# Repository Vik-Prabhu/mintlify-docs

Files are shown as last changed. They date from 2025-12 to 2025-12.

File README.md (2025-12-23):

# Smart Fault Detector

## Project Description

The **Smart-Fault-Detector** is a specialized diagnostic device engineered to detect actuator faults and failures in high-stakes systems like rockets and robotics. By monitoring the "pulse" of an actuator through electrical and mechanical sensors, it identifies anomalies before they lead to catastrophic system failure.

## 📘 Project Documentation & Deployment

### 🌐 Documentation (Mintlify)

This project uses **Mintlify** to host clean, modern documentation.

- Built using MDX
- Supports images, code blocks, and downloadable assets
- Automatically deployed on every update

**Documentation URL:**  https://teamrobomanipal-3a657712.mintlify.app/Introduction

````
To run docs locally:
npm install
mintlify dev
````

---

### 🚀 Backend Deployment (Render + Flask)

The backend is a **Flask + Socket.IO** server deployed on **Render**.

#### Why Render?

- Free tier support
- Simple GitHub integration
- Works well with Flask APIs
- Public endpoint accessible by ESP devices

#### Tech Stack

- Python
- Flask
- Flask-SocketIO
- Eventlet
- Render Web Service

#### Deployment Flow

1. Push code to GitHub
2. Create a **Web Service** on Render
3. Render installs dependencies from `requirements.txt`
4. App runs on a public HTTPS URL

 **Dashboard URL:** https://mintlify-docs-w26p.onrender.com

---

### 📡 ESP ↔ Server Communication

- ESP device sends data via HTTP / Socket.IO

- Flask server receives and processes data

- Real-time updates supported using WebSockets
- Designed for low-latency actuator/health monitoring

---

### 📂 Key Files

```text
.
├── Firmware            # Contains ESP32-C3 Code
├── PCB                 # KiCAD Design Files
```

```
.
├── docs.json             # Contains structured metadata for the project 
├── package-lock.json     # Auto-generated file for mintlify
```

```
Dashboard_src
├── server.py              # Webserver UI
├── health_model.py        # Predictive Algorithm
├── requirements.txt       # Python dependencies
```

---

### 🛠️ requirements.txt

```txt
flask
flask-socketio
eventlet
```

---

### ✅ Status

- [x] Backend deployed on Render
- [x] Documentation live on Mintlify
- [x] ESP integration working

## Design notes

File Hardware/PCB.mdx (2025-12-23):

---
title: "PCB"
---
#  Hardware Architecture Breakdown

---

## 1. Overview
The Smart Fault Detector is a modular health-monitoring device designed to detect actuator faults and failures in mission-critical environments such as rockets, rovers, and base stations. It fuses electrical telemetry such as voltage and current drawn by the actuator with mechanical data such as rpm and vibration around the actuator to determine if an actuator is operating within safety parameters and predicts the estimated time to failure.

---

## 2. Schematics
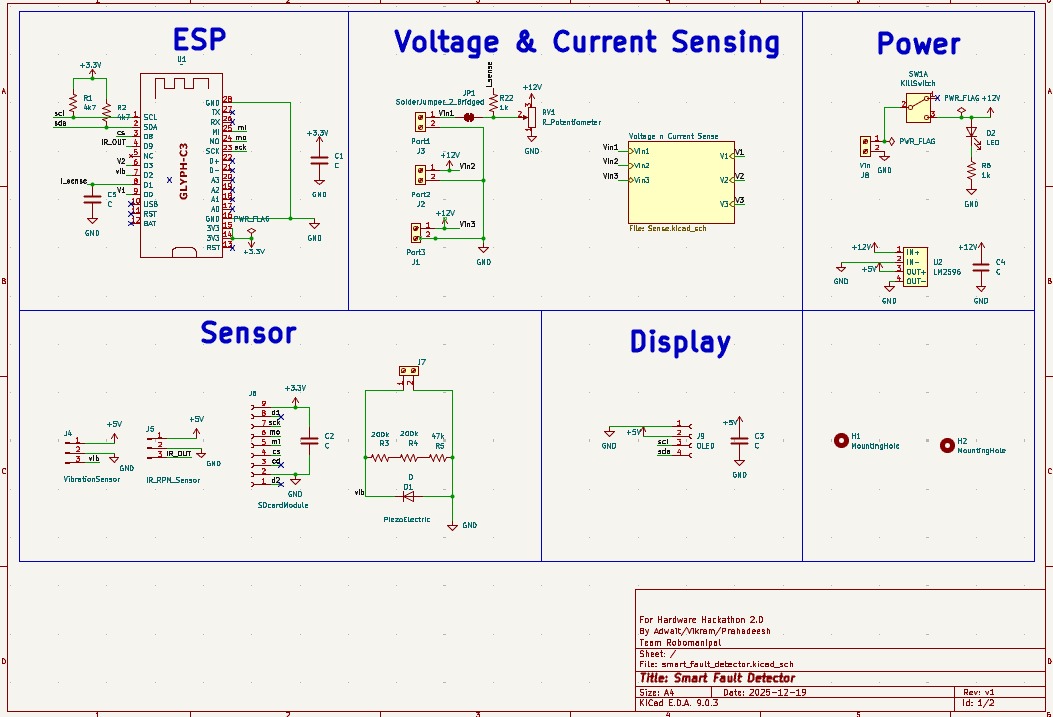
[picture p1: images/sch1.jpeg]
    
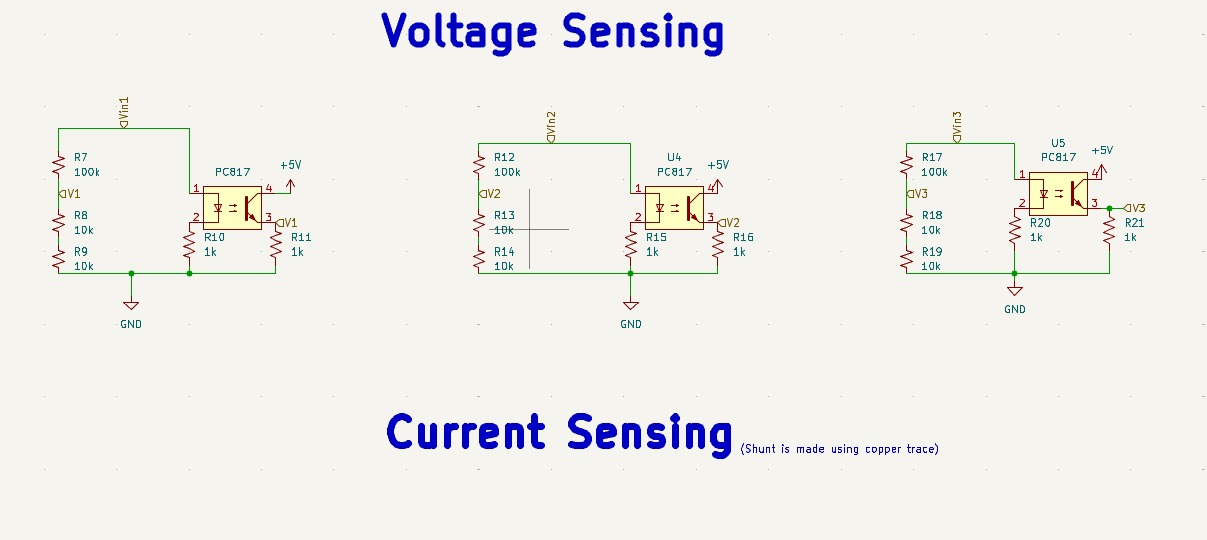
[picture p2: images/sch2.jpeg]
    
    <a href="/assets/gerber.zip" download>
    Download PCB Gerber
    </a>    

### 2.2 3D Printed case
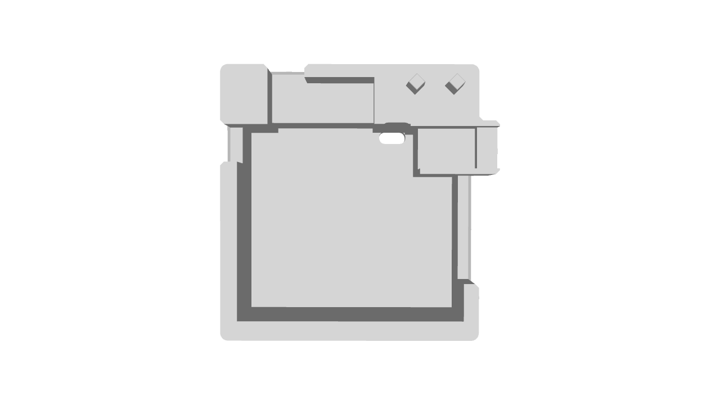
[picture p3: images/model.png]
Model
    
    <a href="/assets/Part1.stl" download>
    Download Part1 STL
    </a>
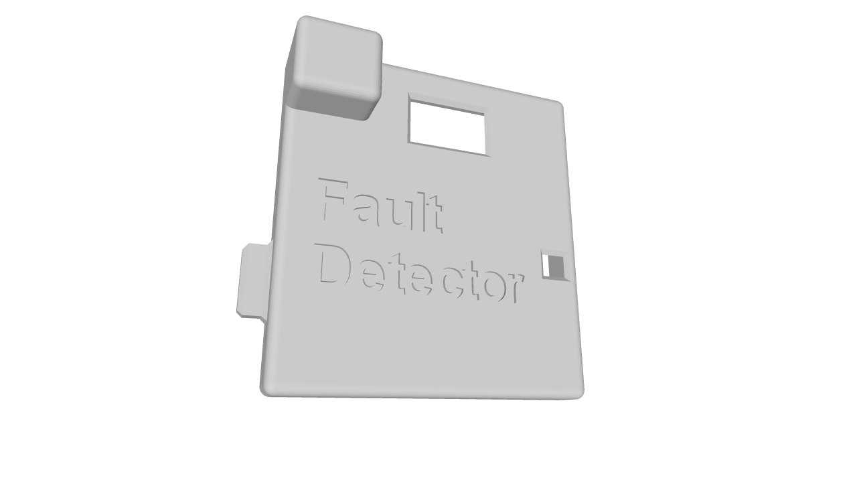
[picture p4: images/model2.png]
Model
    
    <a href="/assets/Part2.stl" download>
    Download Part2 STL
    </a>
---

## 3. Key Features
1. Current sensing - Upto 2A using the PCB trace shunt for 1 channel. 
2. Voltage Sensing - Using voltage divider/using optocoupler (for electrical isolation)
3. Tachometer - To measure RPM of the actuator 
4. Vibration Sensor - To measure mechanical degradtion due to vibrations
5. Dashboard - ESP32 broadcasts the previous logged and live data using WiFi
6. A SD card is present to log data and can be used to debug after major failure
---

## 4. Application
Any system which needs to be robust and needs maintenance - like rovers and other AGV (Autonomous Guided Vehicles) etc

---

## 5. Modules required 

- GLYPH-C3 (ESP32-C3) Development Board
- MicroSD Card Module
- LM2596 Buck Converter
- PC817 Optocoupler
- IR Sensor
- Piezoelectric Element
- 0.96-inch OLED Display

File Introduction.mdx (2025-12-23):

# Smart-Fault-Detector 

##  Project Description
The **Smart-Fault-Detector** is a specialized diagnostic device engineered to detect actuator faults and failures in high-stakes systems like rockets and robotics. By monitoring the "pulse" of an actuator through electrical and mechanical sensors, it identifies anomalies before they lead to catastrophic system failure.
Demo animation

---

##  Hardware Architecture

The system is built around the **GLYPH-C3 (ESP32-C3)** microcontroller. The architecture is divided into modular blocks for power management, sensing, and user interface.
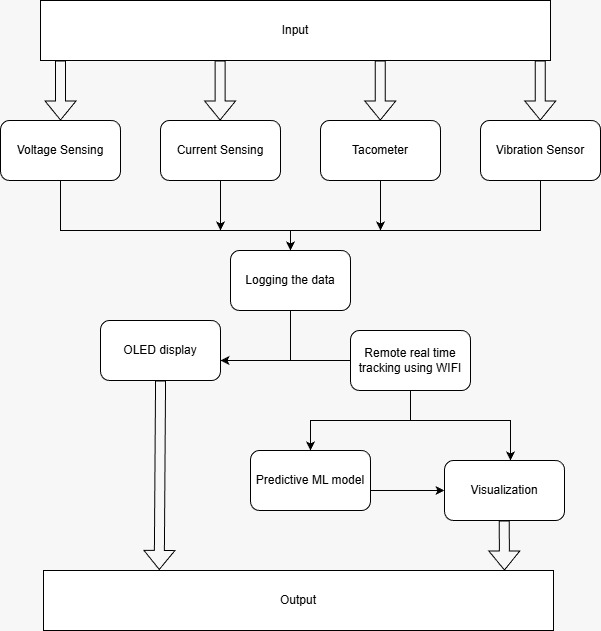
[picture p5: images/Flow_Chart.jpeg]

*Figure 1: Flow-Chart*

---

##  Sensing Implementation
| Feature | Implementation | Purpose |
| :--- | :--- | :--- |
| **Voltage** | Opto-isolated (PC817) Divider | Safely measures high-voltage rails up to 12V with optical isolation. |
| **Current** | **Copper Trace Shunt** | Cost-effective and efficient current measurement via voltage drop. |
| **RPM** | IR Sensor | Non-contact measurement of rotational speed. |
| **Vibration**| Piezoelectric Sensor | Monitors mechanical impacts and high-frequency wear. |

---

##  Web Dashboard & Data Logging
The Smart-Fault-Detector ensures data is never lost, whether you are monitoring it live or analyzing it after a flight. [Preview](https://mintlify-docs-w26p.onrender.com)

* **Logging:** MicroSD card module for real-time data logging and post-failure forensics.
* **IoT Dashboard:** A mobile-responsive web server hosted on the ESP32-C3 featuring:
    * **Live Graphs:** Real-time telemetry for Voltage and Current.
    * **Wear & Tear Tracking:** Predictive analysis based on vibration patterns.
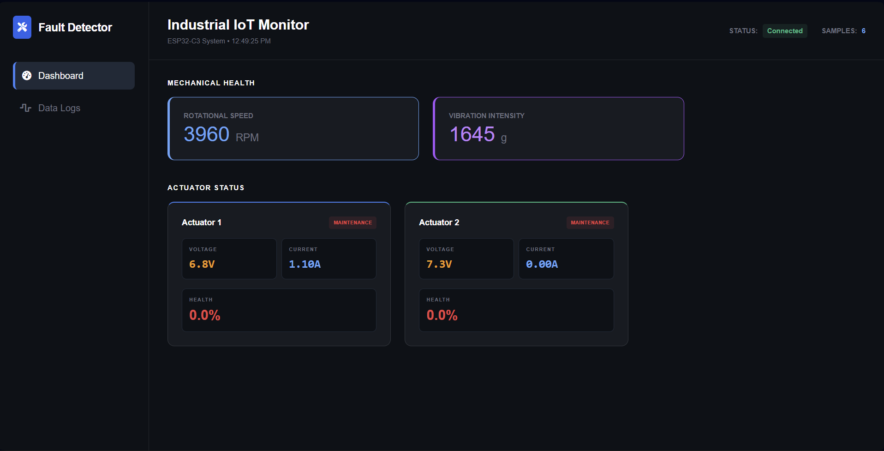
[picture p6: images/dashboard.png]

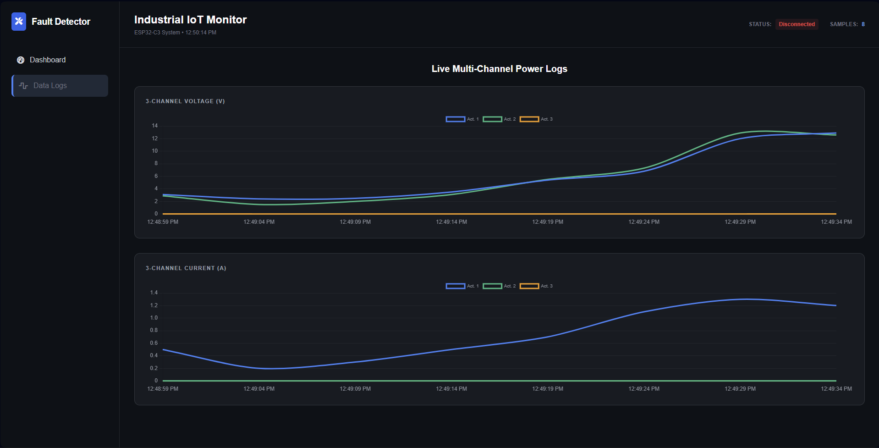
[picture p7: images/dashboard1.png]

---

## Technical Specifications
* **Microcontroller:** ESP32-C3 (RISC-V).
* **Nominal Input:** 12V DC.
* **Nominal Curernt Draw:** 2A.

---

##  [Team Robomanipal](https://robomanipal.com)
* **Project Created At:** Hardware Hackathon 2.0 , Bangalore
* **Developers:** [Adwait](https://github.com/Addwaaait), [Vikram](https://github.com/Vik-Prabhu), [Prahadeesh](https://github.com/tprahadeesh)
* **Release Date:** December 2025

---
© 2025 Team 3 Hardware Hackathon 2.0. All Rights Reserved.

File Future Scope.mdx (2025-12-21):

# Our Vision: Reliability Beyond Earth

Our vision is to redefine how space-grade actuators are monitored. By bridging the gap between historical data logging and real-time predictive maintenance, we are building the "nervous system" for the next generation of space exploration hardware.

---

## Inspiration: From Flight Decks to the Workshop

Our product didn't just appear in a vacuum. It is the result of observing high-stakes aviation systems and solving real-world failures in the lab.

### 1. The "Black Box" Philosophy
In aviation, the Flight Data Recorder (FDR) is the ultimate source of truth. We’ve adopted this "Black Box" architecture for space applications.
* **Data Logging:** Continuous recording of **Voltage, Current, Vibration, and RPM**.
* **Predictive Analysis:** Unlike traditional recorders that tell you what *happened*, our system analyzes trends to tell you what *will* happen, flagging when a motor requires repair before it fails.

### 2. Aviation Fault Detection & Display
Modern aircraft use centralized systems to alert pilots to faults instantly. We are bringing that level of transparency to space robotics.
> **The Goal:** No more "silent failures." Our Fault Detector provides a clear, actionable status of the motor’s health, inspired by the primary flight displays used by pilots.

[Image of an aircraft cockpit engine instrument and crew alerting system (EICAS) display]

### 3. Practical Resilience: The RoboManipal Experience
Real-world engineering taught us our most valuable lesson. While building complex robots, we faced recurring **Back EMF** issues that catastrophicly burnt our hardware.
* **The Solution:** This led to our "Safety-First" PCB design. 
* **Isolation:** We integrated **Optocouplers** for total galvanic isolation, ensuring that the high-power motor side never compromises the delicate logic circuitry.

[Image of an optocoupler circuit diagram for electrical isolation]

### 4. Mars Rover Autonomy
We draw inspiration from planetary rovers like *Curiosity* and *Perseverance*, which must monitor their own "active health" millions of miles from the nearest mechanic. Our product mirrors this autonomy, ensuring that a robot can diagnose itself in the harshest environments.

---

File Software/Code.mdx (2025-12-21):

---
title: 'ESP32-Code'
description: 'Description of Functions and Variables'
---
## 2.1 Sensor Data Acquisition (readSensors)

The `readSensors()` function is the core data-collection routine. It translates physical electrical signals—captured via the Microcontroller's GPIO and Analog-to-Digital Converter (ADC)—into calibrated numerical values used for system monitoring.

Vibration Sensing: Captures a Analog signal from the piezoelectric sensor to identify mechanical movement or impact.

ADC Normalization: Divides raw 12-bit analog values by 4095.0 to create a precise 0 to 1 scaling ratio.

Voltage Conversion: Multiplies the ratio by 3.3 to find the actual voltage present at the microcontroller pin.

Hardware Scaling: Applies a 6.0x multiplier to compensate for external voltage dividers, revealing the true high-side battery voltage.

Current Monitoring: Reads the direct voltage output from the Shunt resisstor.

```cpp
void readSensors() {
    // Capture the binary state of the vibration sensor
    vibState = analogRead(VIB_PIN);
    
    // Read and scale Voltage Pins (2 channels: e.g., Battery and Bus)
    for (int i = 0; i < 2; i++) {
        v_buffer[i] = (analogRead(vPins[i]) / 4095.0) * 3.3 * 6.0;
    }

    // Read and scale Current Pin (1 channel)
    for (int i = 0; i < 1; i++) {
        i_buffer[i] = (analogRead(iPins[i]) / 4095.0) * 3.3;
    }
}

```
### 2.2 WiFi Event Handling Logic

The `WiFiEvent()` function is a callback mechanism that monitors the status of the wireless connection asynchronously, ensuring the system can respond to network changes without blocking other tasks.

Event-Driven Listener: This function triggers automatically whenever the WiFi state changes, acting as an asynchronous monitor for your connection status.

Identifying the State: The switch statement checks the incoming event signal to determine if the device has successfully obtained an IP or lost its connection.

Success Logic: When STA_GOT_IP occurs, it sets wifiConnected to true and prints a success message, signaling that the device is ready for network tasks.

Disconnection Logic: If STA_DISCONNECTED is detected, it sets the status to false and alerts the user via the Serial Monitor that a retry is in progress.

Global Status Management: By updating the wifiConnected flag, this code provides a reliable "safety check" for other functions that need to know if the network is available.

```cpp
void WiFiEvent(WiFiEvent_t event) {
    switch (event) {
        case ARDUINO_EVENT_WIFI_STA_GOT_IP:
            wifiConnected = true;
            Serial.println("WiFi Connected");
            break;

        case ARDUINO_EVENT_WIFI_STA_DISCONNECTED:
            wifiConnected = false;
            Serial.println("WiFi Disconnected, retrying...");
            break;

        default:
            break;
    }
}
```
### 2.3 RPM Calculation and Interrupt Logic

This module utilizes hardware interrupts to accurately measure the rotations per minute (RPM) of a motor or shaft. By using interrupts, the system ensures that high-speed pulses from an IR sensor are never missed, even while the main program is busy with other tasks.

Hardware Interrupts (IRAM_ATTR) Standard code runs line-by-line. However, a motor spinning at high speed might trigger the sensor while the CPU is busy elsewhere. An Interrupt pauses the main code for a fraction of a microsecond to record the pulse. The IRAM_ATTR attribute ensures the function is stored in internal RAM for the fastest possible execution.

If the motor is spinning while the code is trying to reset pulseCount = 0, the count might increment at that exact moment (a "race condition"). We briefly detach the interrupt to "freeze"

Calculation: If the sensor detects 10 pulses in 1 second, the math becomes 10 pulses/sec X 60 = 600 RPM

```cpp
// 1. Calculate RPM every 1 second
if (currentMillis - lastRpmCalc >= 1000) {
    detachInterrupt(digitalPinToInterrupt(IR_PIN));
    currentRPM = pulseCount * 60; // Assumes 1 pulse per revolution
    pulseCount = 0;
    lastRpmCalc = currentMillis;
    attachInterrupt(digitalPinToInterrupt(IR_PIN), countPulse, FALLING);
}

void IRAM_ATTR countPulse() {
    pulseCount++;
}
```
### 2.4 Cloud Data Transmission (JSON Upload)

The `uploadJSON()` function packages the processed sensor data into a structured format and transmits it to a remote server using the HTTP POST protocol.

JSON (JavaScript Object Notation) is used for this project because it is a lightweight, human-readable data format that is the industry standard for web APIs.

Standardization: Almost every web server (Node.js, Python, Firebase) can parse JSON automatically.

Scalability: We can easily add new sensor types (like temperature or humidity) to the doc without breaking the existing server logic.

Key-Value Pairs: It allows us to label our data (e.g., "rpm": 1500), making it much easier to debug than a raw string of comma-separated numbers.

Detailed Breakdown for New Developers
1. Managing Memory with StaticJsonDocument Unlike standard variables, JSON objects can consume significant RAM. We use StaticJsonDocument 512 to pre-allocate a specific amount of memory on the "stack." This prevents the system from crashing due to memory fragmentation during long-term operation.

2. The Nested Array Structure The code creates a JsonArray called ports. Inside this array, we nest JsonObject items. This allows the dashboard to display data for "Port 1" and "Port 2" separately while keeping them under a single parent object.

3. Type Safety (String Conversion) The use of serialized(String(v[j], 1)) ensures that floating-point numbers are sent with exactly one decimal place. This keeps the message size small and consistent for the server.

```cpp
void uploadJSON(float v[], float i_arr[], int vib, int rpm) {
    HTTPClient http;
    http.begin(serverURL);
    http.addHeader("Content-Type", "application/json");

    StaticJsonDocument<512> doc;
    JsonArray ports = doc.createNestedArray("ports");
    
    for (int j = 0; j < 2; j++) {
        JsonObject p = ports.createNestedObject();
        p["port"] = j + 1;
        p["voltage"] = serialized(String(v[j], 1));

        if (j < 1) {
            p["current"] = serialized(String(i_arr[j], 1));
        } else {
            p["current"] = 0;
        }
    }
    
    doc["vibration"] = vib;
    doc["rpm"] = rpm;

    String payload;
    serializeJson(doc, payload);
    
    int httpResponseCode = http.POST(payload);
    Serial.printf("HTTP Response code: %d\n", httpResponseCode);
    
    http.end();
}
```
### 2.5 Local Display Interface (OLED Update)

The `updateOLED()` function provides real-time visual feedback to the user. It formats sensor data—including voltage, current, vibration status, and RPM—into a structured layout on a 128x64 SSD1306 OLED display.

The Buffer Concept The OLED library uses a "back-buffer." When you call functions like setCursor or printf, nothing happens on the screen immediately. Instead, you are "drawing" on a map in the MCU's memory. The display.display() command at the end is what actually sends that map to the screen via I2C.

```cpp
void updateOLED(int port, float v, float i, int vib) {
    display.clearDisplay();
    
    // 1. Header (Inverted color for emphasis)
    display.fillRect(0, 0, 128, 14, SSD1306_WHITE);
    display.setTextColor(SSD1306_BLACK);
    display.setCursor(4, 3);
    display.setTextSize(1);
    display.printf("PORT %d | RPM: %d", port, currentRPM);

    // 2. Main Values (Large text for readability)
    display.setTextColor(SSD1306_WHITE);
    display.setCursor(0, 22);
    display.setTextSize(2);
    display.printf("%.1fV", v);
    display.setCursor(70, 22);
    display.printf("%.1fA", i);

    // 3. Footer (System status)
    display.drawFastHLine(0, 42, 128, SSD1306_WHITE);
    display.setTextSize(1);
    display.setCursor(0, 50);
    display.printf("VIB: %s", vib ? "ACTIVE" : "OK");
    display.setCursor(85, 50);
    display.printf("[%s]", wifiConnected ? "WiFi" : "OFF");
    
    display.display();
}

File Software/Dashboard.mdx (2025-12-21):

---
title: Dashboard
description: Technical overview of the Flask-based IoT Fault Detector Web Server
---

## 1. System Architecture

The server operates on a "Push-Stream" model to ensure low-latency data visualization.

* **Ingestion**: The hardware (ESP32) sends a JSON payload to the `/update` endpoint via HTTP POST.
* **Broadcasting**: The server emits a `sensor_update` event to all connected web clients via SocketIO.
* **Visualization**: The browser receives the data and updates the charts and health indicators dynamically.

---
## 2. Development Setup

### Backend Dependencies:

The backend is built on the Python ecosystem. These packages manage the web server, API routing, and real-time data broadcasting.

* **Flask**: The core micro-framework used for web routing and serving the HTML interface.
* **Flask-SocketIO**: Enables low-latency, bi-directional communication between the server and the dashboard via WebSockets.
* **eventlet or gevent**: (Recommended) High-concurrency libraries often used as the underlying server for SocketIO.

#### Installation:
You can install these dependencies using `pip`:

```bash
pip install flask flask-socketio
```

---

## 3. API Reference

### Data Update Endpoint
`POST /update`

The primary data entry point for the IoT hardware.

**Request Body:**
```json
{
  "ports": [
    {
      "port": 1,
      "voltage": 12.5,
      "current": 0.8
    },
    {
      "port": 2,
      "voltage": 12.4,
      "current": 0
    }
  ],
  "vibration": 5,
  "rpm": 1500
}
```
    <a href="server.py" download>
    Download Server Python Script
    </a> 
---

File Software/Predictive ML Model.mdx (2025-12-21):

---
title: Predictive ML Model
description: Technical overview of the tinyML (rule-based ML) Model
---

This project provides a **Rule-Based Diagnostic System** to calculate the health percentage of an industrial actuator based on real-time sensor data. It evaluates electrical and mechanical stress factors to provide a predictive maintenance score.

## Overview of Metrics

The calculator uses three primary sensor inputs to determine the degradation of the hardware:

1.  **Current (A):** Measures electrical load and resistance.
2.  **Voltage (V):** Monitors power stability and supply quality.
3.  **Vibration (g):** Detects mechanical wear, bearing failure, or misalignment.

---

## Logic & Ruleset

The health score starts at **100.0%** and is reduced based on the following logic:

| Rule | Trigger | Penalty |
| :--- | :--- | :--- |
| **Current Increase** | Every 1.0A above baseline | -3.0% |
| **Voltage Deviation** | Deviation from target (e.g., 220V) | Proportional (up to 20%) |
| **Vibration** | Every 1.0g above baseline | -8.0% |
| **Trend Analysis** | Rapid spikes in Current or Vibration | -5.0% each |
| **Cross-Correlation** | High Current **AND** High Vibration | -15.0% (Severe Alert) |
| **Efficiency** | Power consumption > 120% of expected | -8.0% |

---

## Implementation

```python
def calculate_health(current, voltage, vibration, 
                     baseline_current=5.0, 
                     baseline_voltage=220.0, 
                     baseline_vibration=0.5,
                     current_trend=0.0,
                     vibration_trend=0.0):
    
    Calculates health percentage (0-100) based on sensor deviations.
    
    health = 100.0
    
    # 1. Current penalty
    current_increase = max(0, current - baseline_current)
    health -= current_increase * 3.0 
    
    # 2. Voltage deviation penalty
    voltage_deviation = abs(voltage - baseline_voltage)
    health -= (voltage_deviation / baseline_voltage) * 20.0
    
    # 3. Vibration penalty
    vibration_increase = max(0, vibration - baseline_vibration)
    health -= vibration_increase * 8.0 
    
    # 4. Trend penalties
    if current_trend > 0.05: health -= 5.0
    if vibration_trend > 0.02: health -= 5.0
    
    # 5. Cross-sensor correlation (Severe State)
    current_severe = (current - baseline_current) > (0.2 * baseline_current)
    vibration_severe = (vibration - baseline_vibration) > (0.5 * baseline_vibration)
    if current_severe and vibration_severe:
        health -= 15.0
    
    # 6. Power efficiency check
    power = voltage * current
    expected_power = baseline_voltage * baseline_current
    if power > expected_power * 1.2:
        health -= 8.0
    
    return max(0.0, min(100.0, health))

```
<a href="health_model.py" download>
Download tinyML Python Script
</a>

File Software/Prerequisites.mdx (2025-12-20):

---
title: 'Prerequisites'
---

This tutorial covers the firmware implementation for the **GLYPH C3**, focusing on multi-port sensor data acquisition (Voltage, Current, RPM, Vibration), local OLED visualization, and remote logging via JSON over Wi-Fi.

---

## Table of Contents

- [Prerequisites](#prerequisites)
- [Programming the ESP32-C3](#programming-the-esp32-c3)

## Prerequisites

Before you begin coding for the **glyphC3**, you must configure your development environment and install the necessary dependencies.

### 1. Environment Setup
Follow the complete guide below to set up the Arduino IDE and configure the ESP32-C3 board package:
* **[glyphC3 Arduino IDE Setup Guide](https://learn.pcbcupid.com/boards/needs/arduino-ide-setup)**

### 2. Library Installation
Open the **Library Manager** in the Arduino IDE (*Sketch > Include Library > Manage Libraries*) and install the following:

* **ArduinoJson** (by Benoit Blanchon)
* **Adafruit SSD1306** (by Adafruit)
* **Adafruit GFX Library** (by Adafruit)

> [!TIP]
> Libraries such as `WiFi.h`, `HTTPClient.h`, `SPI.h`, `SD.h`, and `Wire.h` are part of the ESP32 core and are installed automatically when you follow the setup guide above.

---

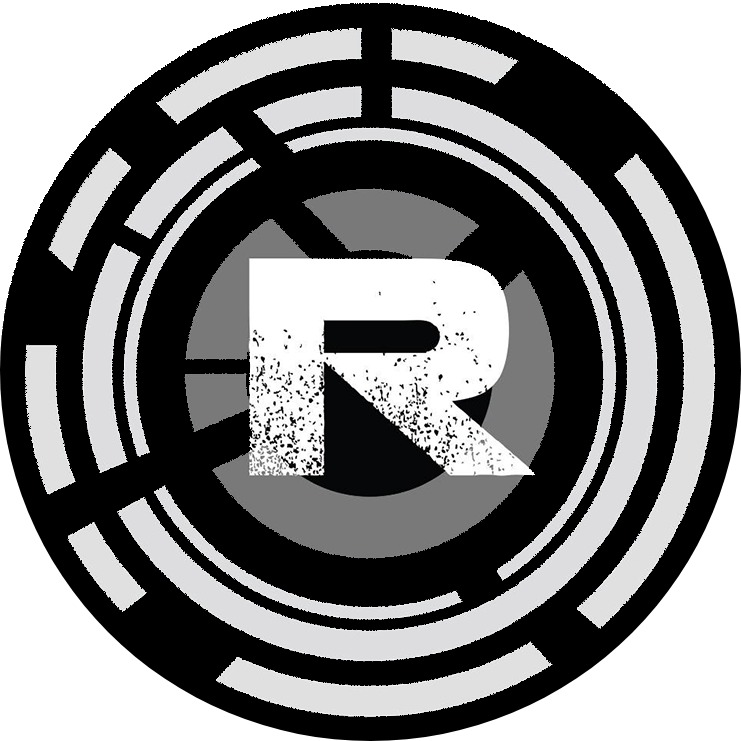
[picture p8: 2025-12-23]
PCB/smart_fault_detector/GlyphC3/IMG-20251008-WA0027 (1).bmp

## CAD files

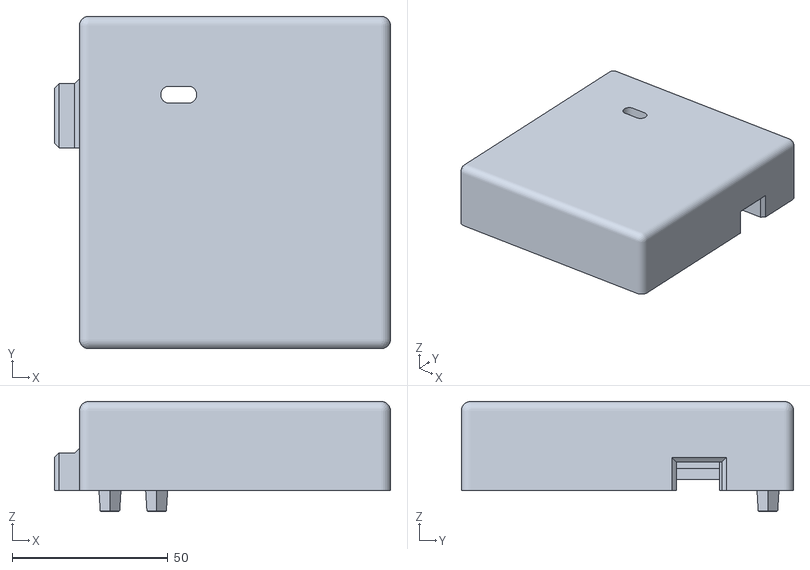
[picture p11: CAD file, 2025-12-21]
assets/Part1.stl
108.0 x 106.8 x 35.4

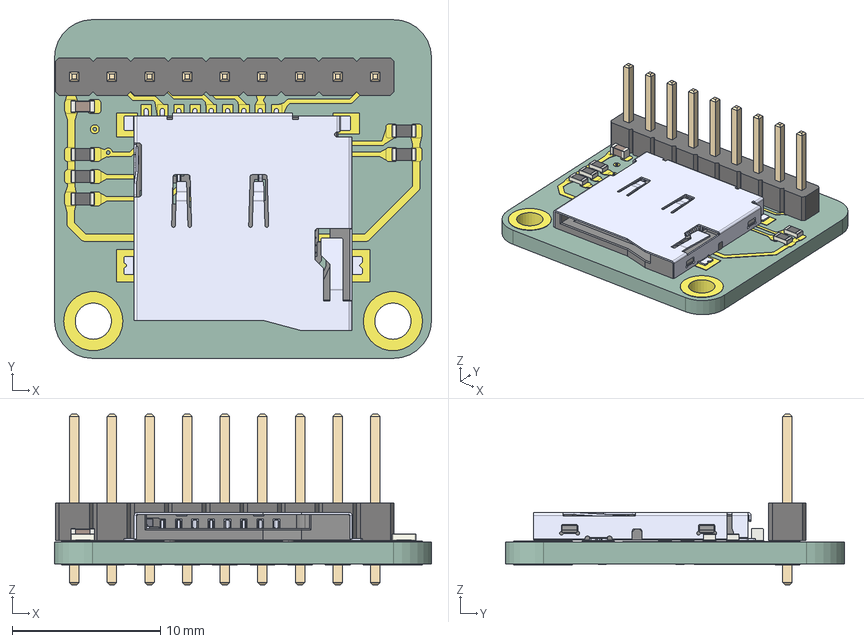
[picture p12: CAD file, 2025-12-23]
PCB/smart_fault_detector/GlyphC3/MicroSD_Card_Module/MICRO-SD-CARD.step
25.4 x 22.9 x 11.5 mm
R_0603_1608Metric x 5
C_0603_1608Metric
ST-TF-003A--3DModel-STEP-56544
PinHeader_1x09_P2.54mm_Vertical
PCBCUPID-MICRO-SD-CARD_copper
PCBCUPID-MICRO-SD-CARD_PCB

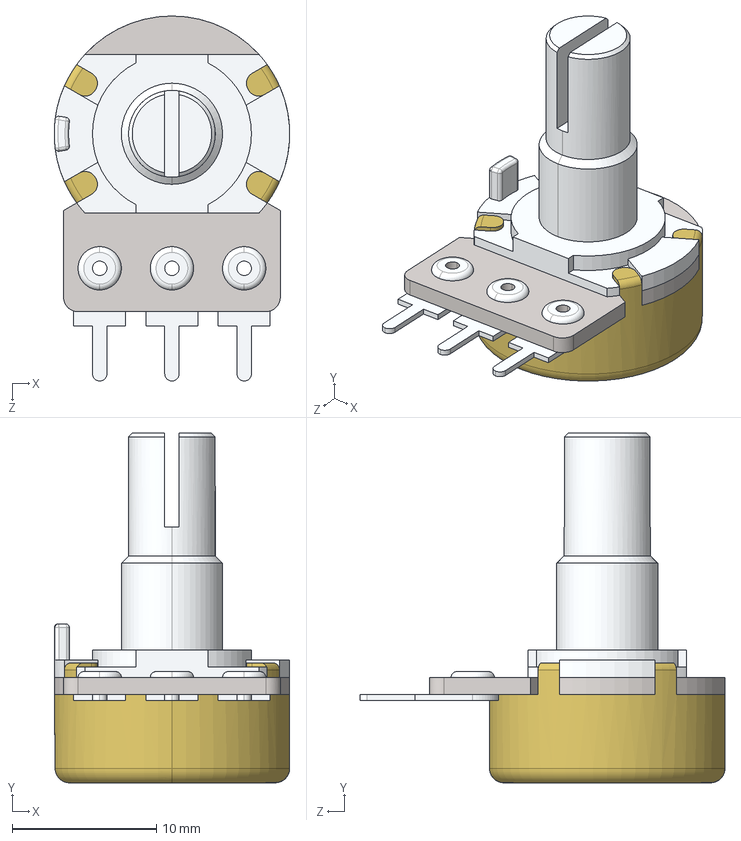
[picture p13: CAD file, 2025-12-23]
PCB/smart_fault_detector/GlyphC3/Potentiometer_10K.STEP
16.3 x 24.2 x 25.3 mm

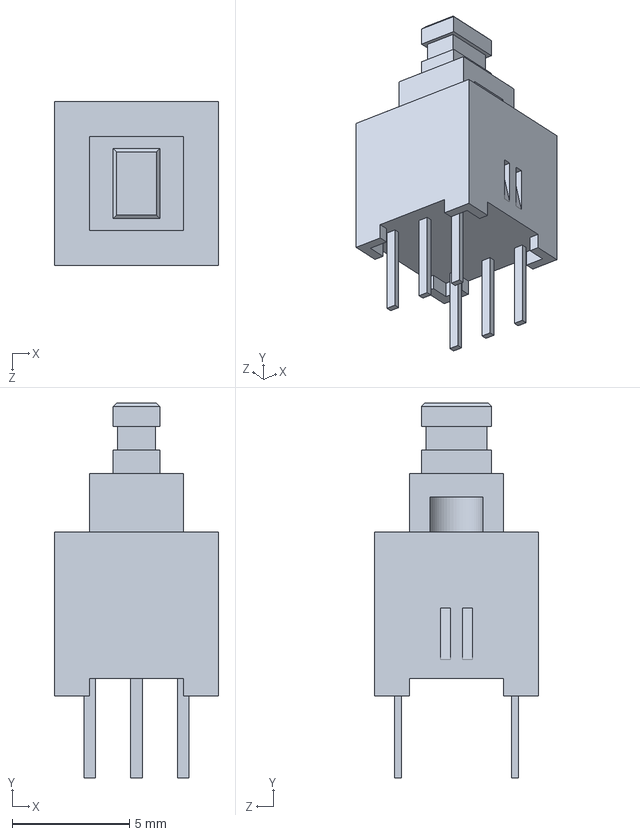
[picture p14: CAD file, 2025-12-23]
PCB/smart_fault_detector/GlyphC3/TL2230EEF140/TL2230EEF140.step
7.00 x 16.0 x 7.00 mm

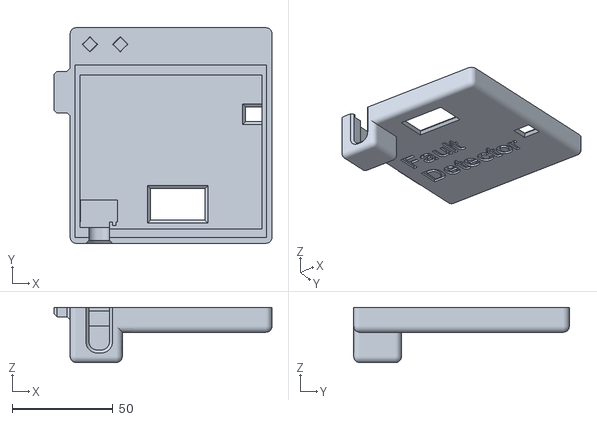
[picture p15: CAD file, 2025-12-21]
assets/Part2.stl
108.0 x 106.8 x 27.3

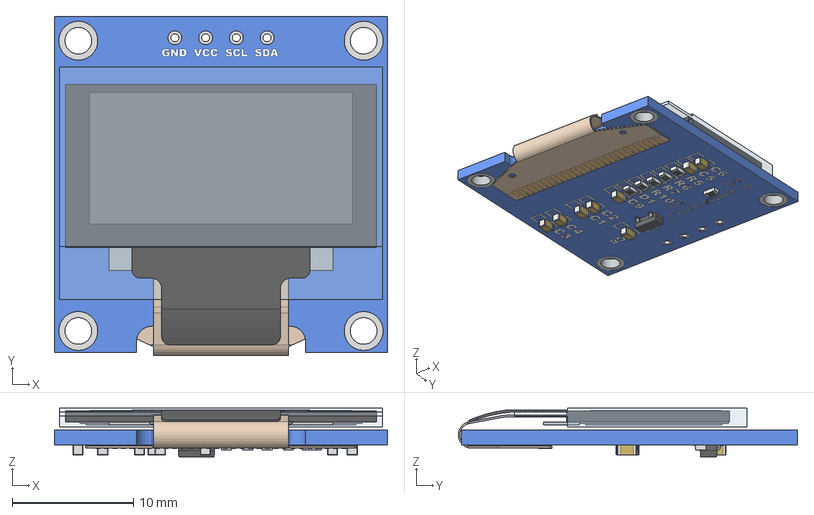
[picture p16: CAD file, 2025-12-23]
PCB/smart_fault_detector/GlyphC3/0.96 OLED Module - i2C.stp
27.5 x 28.0 x 4.03 mm
0.96 OLED - Board - i2c
0.96 OLED - Glass
0.96 OLED - Flat Reverse
0603 Resistor x 6
SOT-23
0603 Capacitor x 8

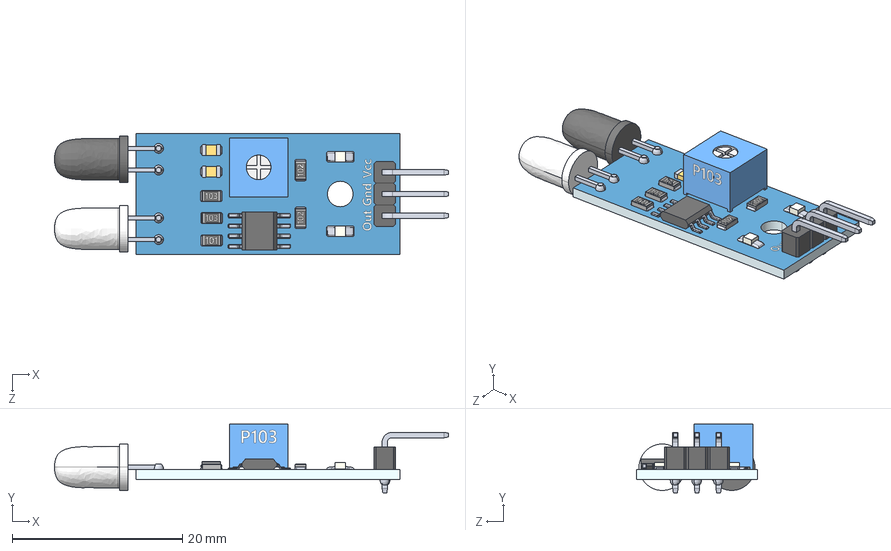
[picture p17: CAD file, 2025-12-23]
PCB/smart_fault_detector/GlyphC3/IRsensors.STEP
46.3 x 8.05 x 14.2 mm
IRboard
solder x 7
90headerMale x 3
blackLEDIRsensor
whiteLEDIRsensor
smdResistor101
smdResistor102 x 2
smdResistor103 x 2
smdceramiccapacitor x 2
smdLED x 2
smdTrimmerP103
smdChip8pin

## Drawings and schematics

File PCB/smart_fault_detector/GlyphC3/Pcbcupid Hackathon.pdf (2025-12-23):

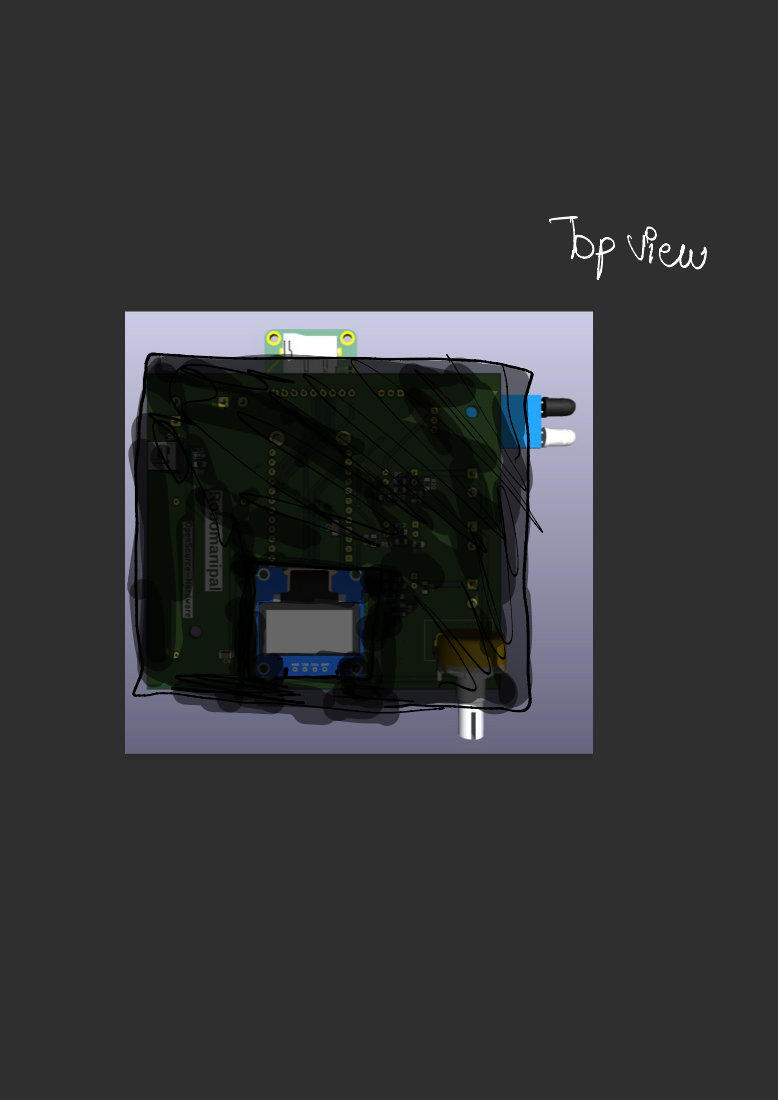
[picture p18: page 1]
Top view

*

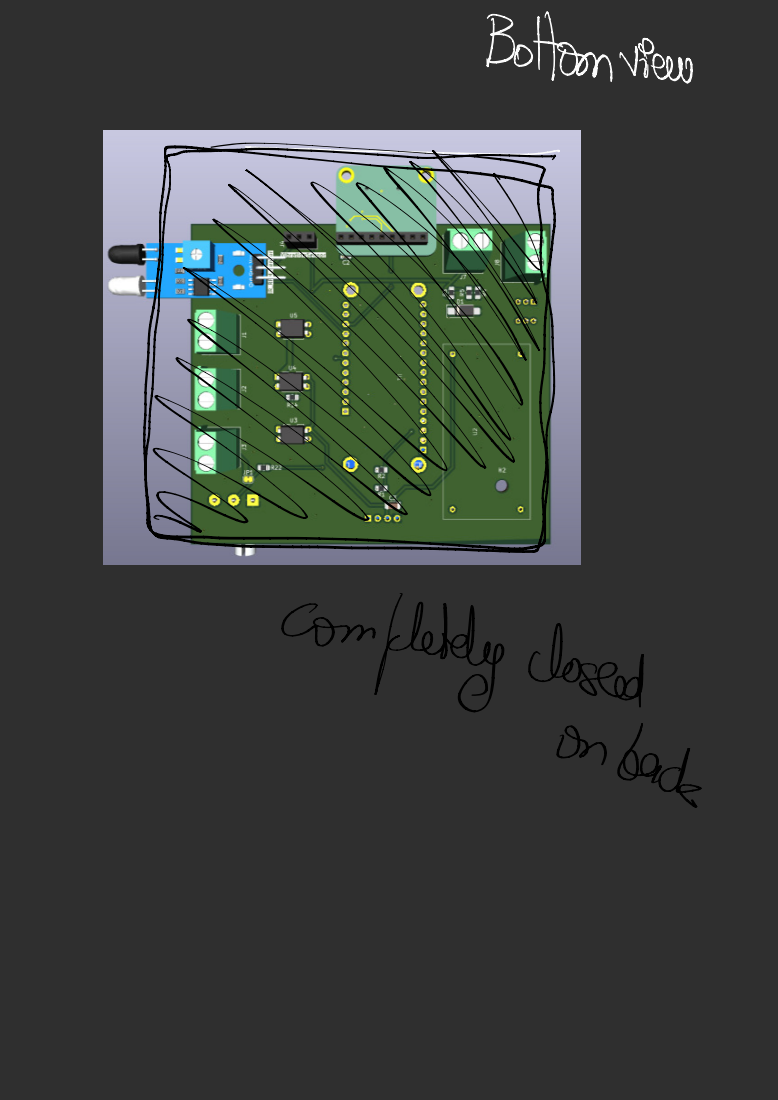
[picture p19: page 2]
Bottom view; completely closed; back

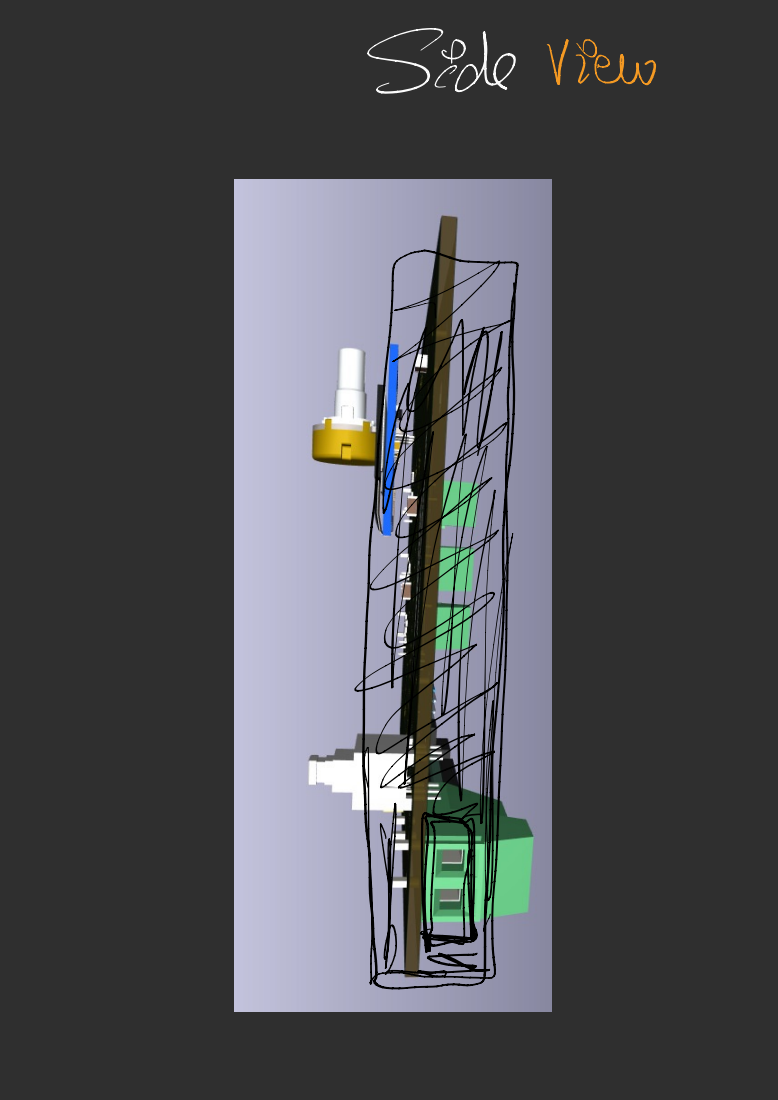
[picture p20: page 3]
Side View 薏

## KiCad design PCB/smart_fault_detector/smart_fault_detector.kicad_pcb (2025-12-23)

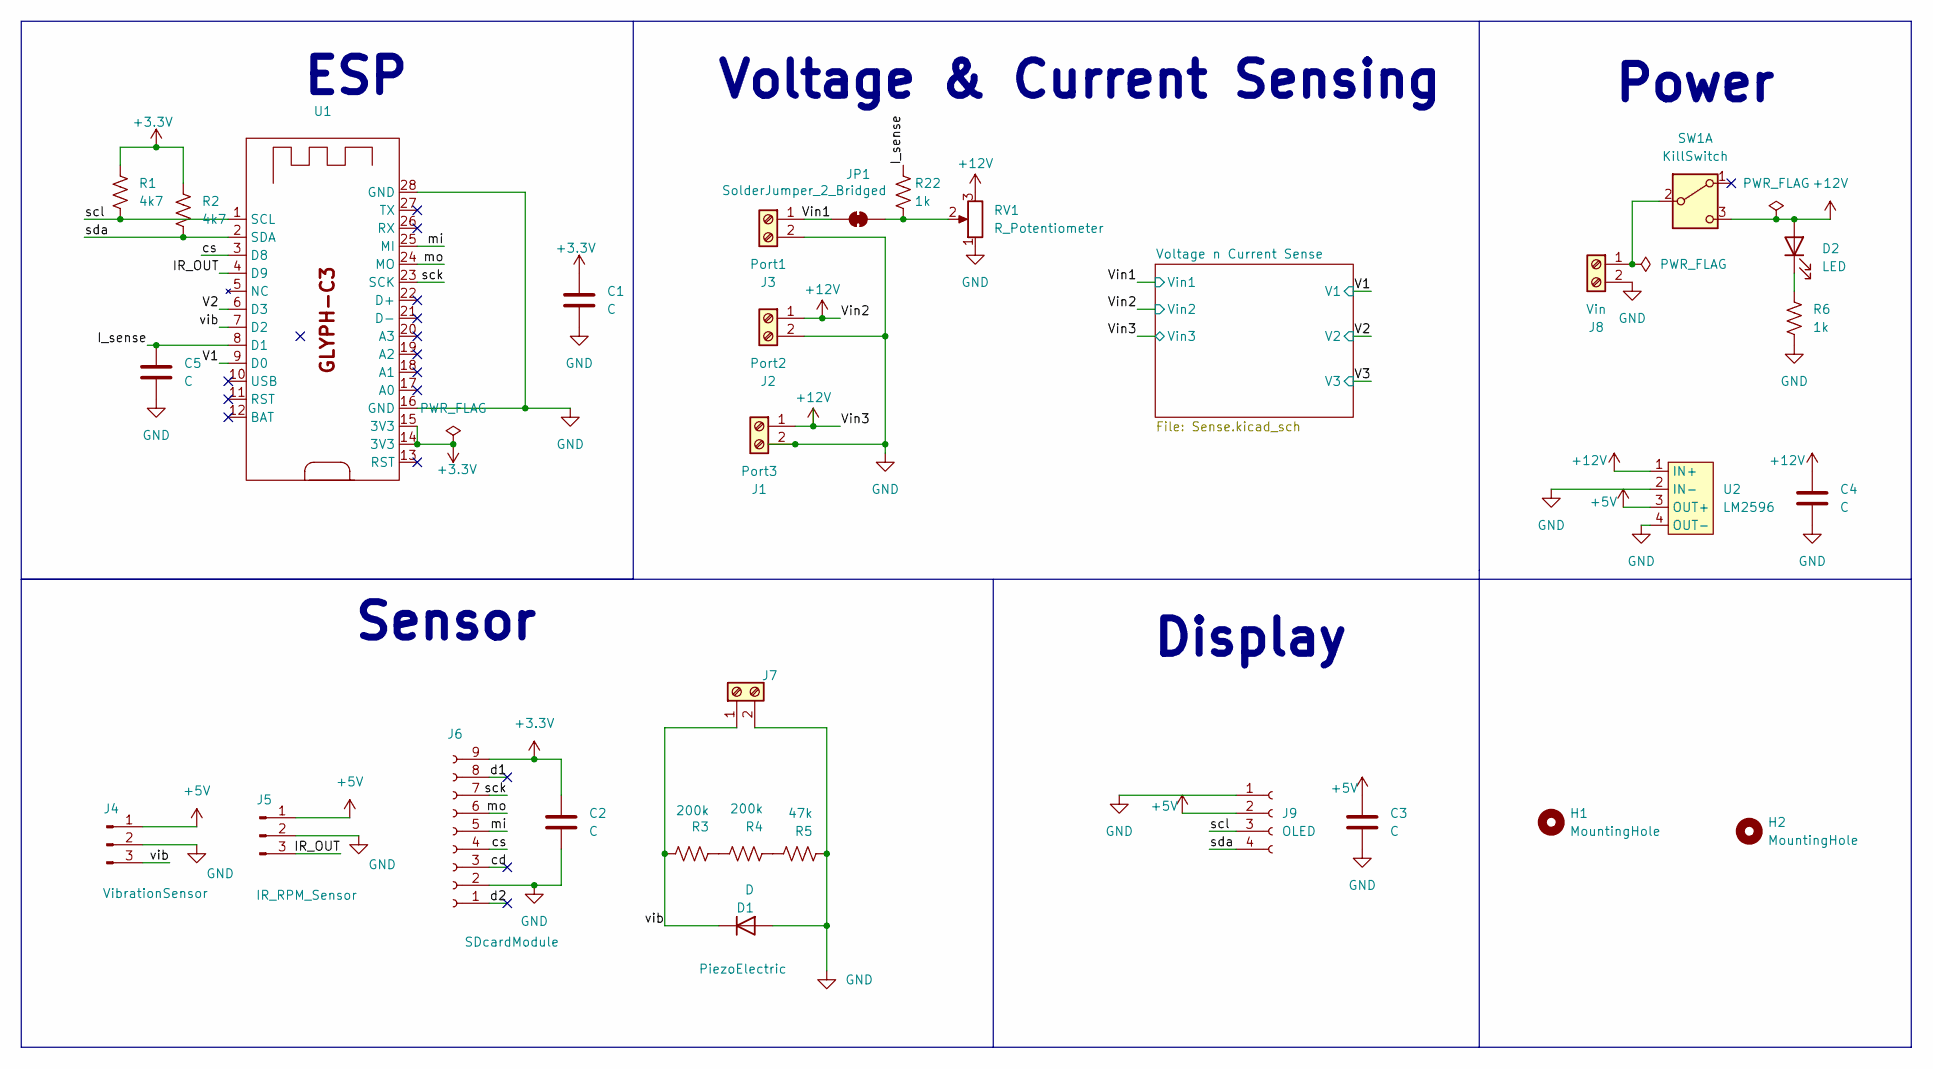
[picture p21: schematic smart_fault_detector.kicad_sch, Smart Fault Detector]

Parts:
C1, C3, C4, C5: C; C_1206_3216Metric
C2: C; C_0603_1608Metric_Pad1.08x0.95mm_HandSolder
D1: D; D_SMA_Handsoldering
D2: LED; LED_0603_1608Metric_Pad1.05x0.95mm_HandSolder
H1, H2: MountingHole; MountingHole_3.2mm_M3
J1: Port3; TerminalBlock_Phoenix_MKDS-1,5-2-5.08_1x02_P5.08mm_Horizont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
J2: Port2; TerminalBlock_Phoenix_MKDS-1,5-2-5.08_1x02_P5.08mm_Horizont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
J3: Port1; TerminalBlock_Phoenix_MKDS-1,5-2-5.08_1x02_P5.08mm_Horizont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
J4: VibrationSensor; PinSocket_1x03_P2.54mm_Vertical
J5: IR_RPM_Sensor; PinSocket_1x03_P2.54mm_Vertical
J6: SDcardModule; PinSocket_1x09_P2.54mm_Vertical
J7: PiezoElectric; TerminalBlock_Phoenix_MKDS-1,5-2-5.08_1x02_P5.08mm_Horizont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
J8: Vin; TerminalBlock_Phoenix_MKDS-1,5-2-5.08_1x02_P5.08mm_Horizont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
J9: OLED; PinSocket_1x04_P2.54mm_Vertical
JP1: SolderJumper_2_Bridged; SolderJumper-2_P1.3mm_Bridged_RoundedPad1.0x1.5mm
R1, R2: 4k7; R_0805_2012Metric_Pad1.20x1.40mm_HandSolder
R3, R4: 200k; R_0805_2012Metric_Pad1.20x1.40mm_HandSolder
R5: 47k; R_0805_2012Metric_Pad1.20x1.40mm_HandSolder
R6, R22: 1k; R_0805_2012Metric_Pad1.20x1.40mm_HandSolder
RV1: R_Potentiometer; Potentiometer_Alps_RK163_Single_Horizontal
SW1: KillSwitch; SW_TL2230EEF140
U1: GlyphC3
U2: LM2596; LM2596_Buck

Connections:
+3.3V: C1.1, C2.1, J6.9, R1.1, R2.1, U1.14 (3V3), U1.15 (3V3)
+5V: C3.1, J4.1, J5.1, J9.2, U2.3 (OUT+); also elsewhere on the board
+12V: C4.1, D2.2 (A), J1.1, J2.1, RV1.3, SW1.3 (C), U2.1 (IN+); also elsewhere on the board
/IR_OUT: J5.3, U1.4 (D9)
/I_sense: C5.1, R22.1, U1.8 (D1)
/V1: U1.9 (D0); also elsewhere on the board
/V2: U1.6 (D3); also elsewhere on the board
/Vin1: J3.1, JP1.1 (A); also elsewhere on the board
/cd: J6.3
/cs: J6.4, U1.3 (D8)
/d1: J6.8
/d2: J6.1
/mi: J6.5, U1.25 (MI)
/mo: J6.6, U1.24 (MO)
/sck: J6.7, U1.23 (SCK)
/scl: J9.3, R1.2, U1.1 (SCL)
/sda: J9.4, R2.2, U1.2 (SDA)
/vib: D1.1 (K), J4.3, J7.1, R3.1, U1.7 (D2)
GND: C1.2, C2.2, C3.2, C4.2, C5.2, D1.2 (A), J1.2, J2.2, J3.2, J4.2, J5.2, J6.2, J7.2, J8.2, J9.1, R5.2, R6.2, RV1.1, U1.16 (GND), U1.28 (GND), U2.2 (IN-), U2.4 (OUT-); also elsewhere on the board
unnamed: D2.1 (K), R6.1
unnamed: J8.1, SW1.2 (B)
unnamed: JP1.2 (B), R22.2, RV1.2
unnamed: R3.2, R4.1
unnamed: R4.2, R5.1

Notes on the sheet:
ESP
Sensor
Voltage & Current Sensing
Power
Display

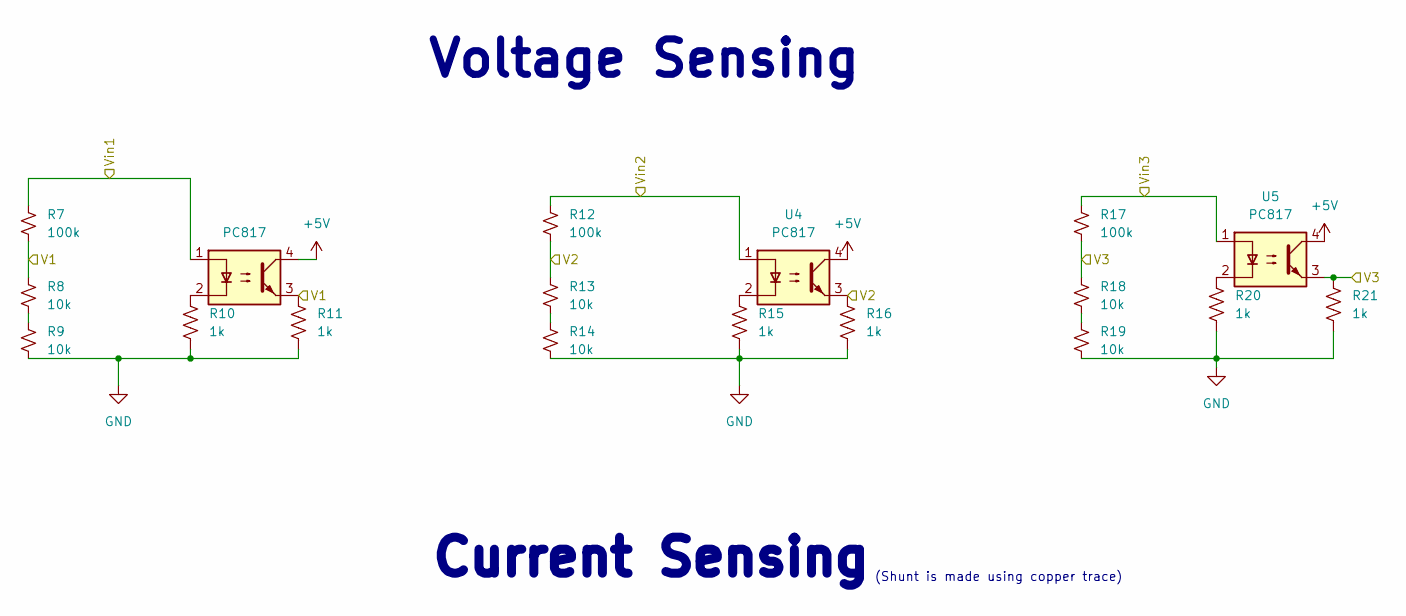
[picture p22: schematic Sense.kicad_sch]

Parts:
R7, R12, R17: 100k; R_0805_2012Metric_Pad1.20x1.40mm_HandSolder
R8, R9, R13, R14, R18, R19: 10k; R_0805_2012Metric_Pad1.20x1.40mm_HandSolder
R10, R11, R15, R16, R20, R21: 1k; R_0805_2012Metric_Pad1.20x1.40mm_HandSolder
U3, U4, U5: PC817; DIP-4_W7.62mm

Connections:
+5V: U3.4, U4.4, U5.4; also elsewhere on the board
+12V: R12.1, R17.1, U4.1, U5.1; also elsewhere on the board
/V1: R7.2, R8.1, R11.1, U3.3; also elsewhere on the board
/V2: R12.2, R13.1, R16.1, U4.3; also elsewhere on the board
/V3: R17.2, R18.1, R21.1, U5.3
/Vin1: R7.1, U3.1; also elsewhere on the board
GND: R9.2, R10.2, R11.2, R14.2, R15.2, R16.2, R19.2, R20.2, R21.2; also elsewhere on the board
unnamed: R8.2, R9.1
unnamed: R10.1, U3.2
unnamed: R13.2, R14.1
unnamed: R15.1, U4.2
unnamed: R18.2, R19.1
unnamed: R20.1, U5.2

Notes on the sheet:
(Shunt is made using copper trace)
Voltage Sensing
Current Sensing

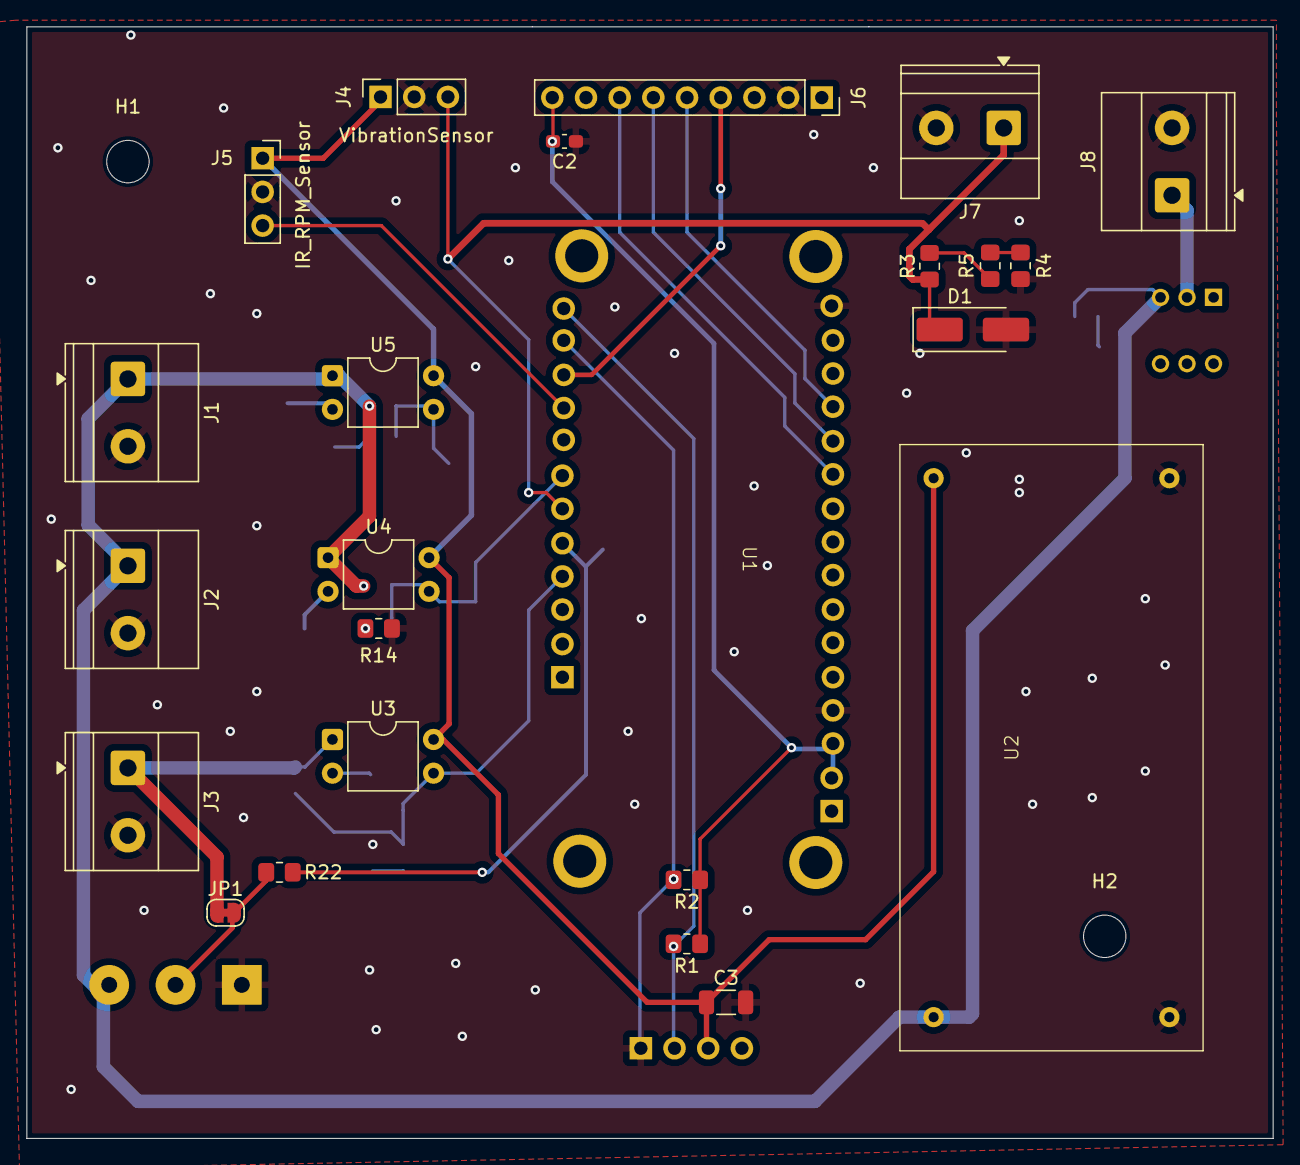
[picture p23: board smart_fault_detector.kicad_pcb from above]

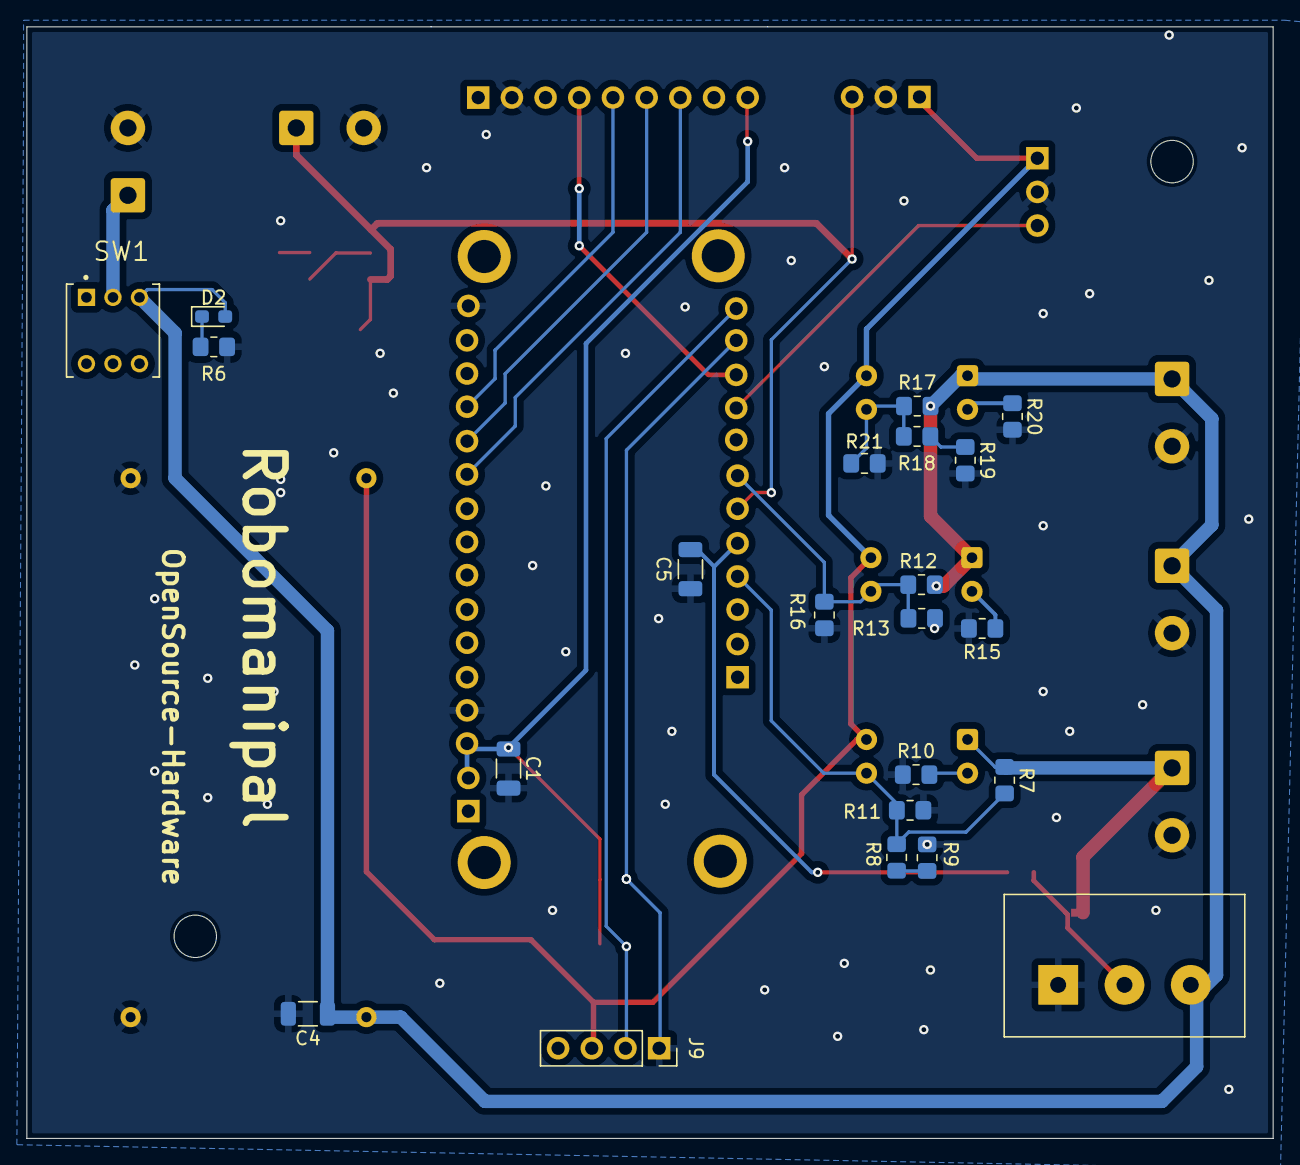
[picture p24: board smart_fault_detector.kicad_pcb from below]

Board: 2 copper layers, 94.0 x 83.8 mm, 48 parts (22 on the bottom side), 28 nets.

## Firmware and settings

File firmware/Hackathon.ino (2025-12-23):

#include <WiFi.h>
#include <HTTPClient.h>
#include <ArduinoJson.h>
#include <SPI.h>
#include <SD.h>
#include <Wire.h>
#include <Adafruit_GFX.h>
#include <Adafruit_SSD1306.h>

/* -------- Pin Definitions (Original - UNCHANGED) -------- */
#define SD_SCK    10   
#define SD_MOSI   6    
#define SD_MISO   7   
#define SD_CS     8  
#define VIB_PIN   2    
#define I2C_SDA   4    
#define I2C_SCL   5    
#define IR_PIN    20

const int vPins[2] = {0, 3};   // Size is 2
const int iPins[1] = {1};      // Size is 1

/* -------- Configuration -------- */
const char* ssid     = "Vik";
const char* password = "qwertyui";
const char* serverURL = "http://192.168.126.250:5000/update";

/* -------- Objects & Globals -------- */
Adafruit_SSD1306 display(128, 64, &Wire, -1);
bool wifiConnected = false;
unsigned long lastUpdate = 0;
const long interval = 5000; 

volatile int pulseCount = 0;
unsigned long lastRpmCalc = 0;
int currentRPM = 0;

// Global sensor buffers
float v_buffer[3] = {0, 0, 0};
float i_buffer[3] = {0, 0, 0};
int vibState = 0;

/* -------- Functions -------- */

void IRAM_ATTR countPulse() {
    pulseCount++;
}

// Note the addition of 'WiFiEventInfo_t info'
void WiFiEvent(WiFiEvent_t event, WiFiEventInfo_t info) {
    switch (event) {
        case ARDUINO_EVENT_WIFI_STA_GOT_IP:
            wifiConnected = true;
            Serial.print("WiFi Connected! IP: ");
            Serial.println(WiFi.localIP());
            break;

        case ARDUINO_EVENT_WIFI_STA_DISCONNECTED: 
        { // <--- ADD THIS BRACE
            wifiConnected = false;
            int reason = info.wifi_sta_disconnected.reason;
            Serial.printf("WiFi Disconnected. Reason Code: %d\n", reason);
        } // <--- ADD THIS BRACE
            break;

        default:
            break;
    }
}

// Large OSHW Logo (48x48) for Splash Screen
const uint8_t image_data[] PROGMEM = {
0x00, 0x00, 0x00, 0x1f, 0xc0, 0x00, 0x00, 0x00, 0x00, 0x00, 0x00, 0x00, 0x00, 0x00, 0x00, 0x00, 
0x00, 0x00, 0x00, 0x18, 0xc0, 0x00, 0x00, 0x00, 0x00, 0x00, 0x00, 0x00, 0x00, 0x00, 0x00, 0x00, 
0x00, 0x00, 0x00, 0x10, 0x40, 0x00, 0x00, 0x00, 0x00, 0x00, 0x00, 0x00, 0x00, 0x00, 0x00, 0x00, 
0x00, 0x00, 0x00, 0x30, 0x40, 0x00, 0x00, 0x00, 0x00, 0x00, 0x00, 0x00, 0x00, 0x00, 0x00, 0x00, 
0x00, 0x00, 0x00, 0x30, 0x60, 0x00, 0x00, 0x00, 0x00, 0x00, 0x00, 0x00, 0x00, 0x00, 0x00, 0x00, 
0x00, 0x01, 0x80, 0x30, 0x60, 0x0c, 0x00, 0x00, 0x00, 0x00, 0x00, 0x00, 0x00, 0x00, 0x00, 0x00, 
0x00, 0x03, 0xe0, 0x20, 0x20, 0x3e, 0x00, 0x00, 0x00, 0x00, 0x00, 0x00, 0x00, 0x00, 0x00, 0x00, 
0x00, 0x06, 0x30, 0xe0, 0x38, 0x63, 0x00, 0x00, 0x00, 0x00, 0x00, 0x00, 0x00, 0x00, 0x00, 0x00, 
0x00, 0x0c, 0x1f, 0x80, 0x0f, 0xc1, 0x80, 0x00, 0x00, 0x00, 0x00, 0x00, 0x00, 0x00, 0x00, 0x00, 
0x00, 0x08, 0x06, 0x00, 0x03, 0x00, 0x80, 0x00, 0x00, 0x00, 0x00, 0x00, 0x00, 0x00, 0x00, 0x00, 
0x00, 0x0c, 0x00, 0x00, 0x00, 0x01, 0x80, 0x00, 0x00, 0x00, 0x00, 0x00, 0x00, 0x00, 0x00, 0x00, 
0x00, 0x04, 0x00, 0x00, 0x00, 0x03, 0x00, 0x00, 0x00, 0x00, 0x00, 0x00, 0x00, 0x00, 0x00, 0x00, 
0x00, 0x02, 0x00, 0x00, 0x00, 0x02, 0x00, 0x00, 0x00, 0x00, 0x00, 0x00, 0x00, 0x00, 0x00, 0x00, 
0x00, 0x03, 0x00, 0x00, 0x00, 0x06, 0x00, 0x00, 0x00, 0x00, 0x00, 0x00, 0x00, 0x00, 0x00, 0x00, 
0x00, 0x01, 0x00, 0x00, 0x00, 0x04, 0x00, 0x00, 0x00, 0x00, 0x00, 0x00, 0x00, 0x00, 0x00, 0x00, 
0x00, 0x01, 0x00, 0x00, 0x00, 0x04, 0x00, 0x00, 0x00, 0x00, 0x00, 0x00, 0x00, 0x00, 0x00, 0x00, 
0x00, 0x03, 0x00, 0x0f, 0x80, 0x06, 0x00, 0x00, 0x00, 0x00, 0x00, 0x00, 0x00, 0x00, 0x00, 0x00, 
0x00, 0x02, 0x00, 0x30, 0x60, 0x02, 0x00, 0x00, 0x00, 0x00, 0x00, 0x00, 0x00, 0x00, 0x00, 0x00, 
0x00, 0x06, 0x00, 0x40, 0x10, 0x03, 0x00, 0x00, 0x00, 0x00, 0x00, 0x00, 0x00, 0x00, 0x00, 0x00, 
0x00, 0x0c, 0x00, 0x80, 0x08, 0x03, 0x80, 0x00, 0x00, 0x00, 0x00, 0x00, 0x00, 0x00, 0x00, 0x00, 
0x01, 0xfc, 0x01, 0x80, 0x0c, 0x01, 0xfc, 0x00, 0x00, 0x00, 0x00, 0x00, 0x00, 0x00, 0x00, 0x00, 
0x01, 0x80, 0x01, 0x00, 0x04, 0x00, 0x0c, 0x00, 0x00, 0x00, 0x00, 0x00, 0x00, 0x00, 0x00, 0x00, 
0x01, 0x00, 0x01, 0x00, 0x04, 0x00, 0x04, 0x00, 0x00, 0x00, 0x00, 0x00, 0x00, 0x00, 0x00, 0x00, 
0x01, 0x00, 0x01, 0x00, 0x04, 0x00, 0x04, 0x00, 0x00, 0x00, 0x00, 0x00, 0x00, 0x00, 0x00, 0x00, 
0x01, 0x00, 0x01, 0x00, 0x04, 0x00, 0x04, 0x00, 0x00, 0x00, 0x00, 0x00, 0x00, 0x00, 0x00, 0x00, 
0x01, 0x00, 0x01, 0x00, 0x04, 0x00, 0x04, 0x00, 0x00, 0x00, 0x00, 0x00, 0x00, 0x00, 0x00, 0x00, 
0x01, 0xe0, 0x01, 0x00, 0x04, 0x00, 0x3c, 0x00, 0x00, 0x00, 0x00, 0x00, 0x00, 0x00, 0x00, 0x00, 
0x00, 0x3c, 0x00, 0x80, 0x08, 0x01, 0xe0, 0x00, 0x00, 0x00, 0x00, 0x00, 0x00, 0x00, 0x00, 0x00, 
0x00, 0x04, 0x00, 0xc0, 0x18, 0x03, 0x00, 0x00, 0x00, 0x00, 0x00, 0x00, 0x00, 0x00, 0x00, 0x00, 
0x00, 0x02, 0x00, 0x60, 0x30, 0x02, 0x00, 0x00, 0x00, 0x00, 0x00, 0x00, 0x00, 0x00, 0x00, 0x00, 
0x00, 0x02, 0x00, 0x30, 0x60, 0x02, 0x00, 0x00, 0x00, 0x00, 0x00, 0x00, 0x00, 0x00, 0x00, 0x00, 
0x00, 0x03, 0x00, 0x20, 0x20, 0x06, 0x00, 0x00, 0x00, 0x00, 0x00, 0x00, 0x00, 0x00, 0x00, 0x00, 
0x00, 0x01, 0x00, 0x20, 0x20, 0x04, 0x00, 0x00, 0x00, 0x00, 0x00, 0x00, 0x00, 0x00, 0x00, 0x00, 
0x00, 0x01, 0x00, 0x40, 0x10, 0x04, 0x00, 0x00, 0x00, 0x00, 0x00, 0x00, 0x00, 0x00, 0x00, 0x00, 
0x00, 0x03, 0x00, 0x40, 0x10, 0x06, 0x00, 0x00, 0x00, 0x00, 0x00, 0x00, 0x00, 0x00, 0x00, 0x00, 
0x00, 0x06, 0x00, 0xc0, 0x18, 0x03, 0x00, 0x00, 0x00, 0x00, 0x00, 0x00, 0x00, 0x00, 0x00, 0x00, 
0x00, 0x04, 0x00, 0x80, 0x08, 0x01, 0x00, 0x00, 0x00, 0x00, 0x00, 0x00, 0x00, 0x00, 0x00, 0x00, 
0x00, 0x08, 0x00, 0x80, 0x08, 0x01, 0x80, 0x00, 0x00, 0x00, 0x00, 0x00, 0x00, 0x00, 0x00, 0x00, 
0x00, 0x0c, 0x0d, 0x00, 0x05, 0x81, 0x80, 0x00, 0x00, 0x00, 0x00, 0x00, 0x00, 0x00, 0x00, 0x00, 
0x00, 0x04, 0x1f, 0x00, 0x07, 0xc3, 0x00, 0x00, 0x00, 0x00, 0x00, 0x00, 0x00, 0x00, 0x00, 0x00, 
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
};
void setup() {
    delay(1000); 
    Serial.begin(115200);

    // WiFi Setup
WiFi.disconnect(true, true);
delay(500);

WiFi.mode(WIFI_STA);
WiFi.setAutoReconnect(true);
WiFi.persistent(false);
WiFi.onEvent(WiFiEvent);
WiFi.begin(ssid, password);



    // Hardware Setup
    pinMode(IR_PIN, INPUT_PULLUP);
    attachInterrupt(digitalPinToInterrupt(IR_PIN), countPulse, FALLING);
    pinMode(VIB_PIN, INPUT_PULLUP);
    
 // 1. Initialize OLED
 // 1. Initialize OLED
Wire.begin(I2C_SDA, I2C_SCL);
    if(!display.begin(SSD1306_SWITCHCAPVCC, 0x3C)) {
        Serial.println(F("SSD1306 allocation failed"));
        for(;;); // Don't proceed, loop forever
    }

    // --- STAGE 1: FULL SCREEN SPLASH ---
    display.clearDisplay();
    // Use 0,0 for full 128x64 alignment
    display.drawBitmap(32, 0, image_data, 128, 64, SSD1306_WHITE);
    display.display();
    delay(2500); // Show splash logo for 2.5 seconds

// --- STAGE 2: DASHBOARD TRANSITION ---
    display.clearDisplay();
    display.drawRect(0, 0, 128, 64, SSD1306_WHITE); // Outer Border
    
    display.setTextSize(2);
    display.setTextColor(SSD1306_WHITE);
    display.setCursor(32, 10);
    display.print("TEAM 3");
    
    display.setTextSize(1);
    display.setCursor(30, 35);
    display.print("Fault Detector");
    

    // IMPORTANT: Push the buffer to the physical screen
    display.display(); 

    SPI.begin(SD_SCK, SD_MISO, SD_MOSI, SD_CS);
    
    if(!SD.begin(SD_CS)) {
        Serial.println("SD Failed");
        // Optional: show "SD ERROR" on screen
    }
    
    delay(2000);
}

// Function to handle sensor reading safely
void readSensors() {
    vibState = analogRead(VIB_PIN);
    
    // Read Voltage Pins (only 2 available)
    for (int i = 0; i < 2; i++) {
        v_buffer[i] = (analogRead(vPins[i]) / 4095.0) * 3.3 * 6.0;
    }
    // Read Current Pins (only 1 available)
    for (int i = 0; i < 1; i++) {
        i_buffer[i] = (analogRead(iPins[i]) / 4095.0) * 3.3;
    }
}

void loop() {
    unsigned long currentMillis = millis();

    // 1. Calculate RPM every 1 second
    if (currentMillis - lastRpmCalc >= 1000) {
        detachInterrupt(digitalPinToInterrupt(IR_PIN));
        currentRPM = pulseCount * 60; // Assumes 1 pulse per revolution
        pulseCount = 0;
        lastRpmCalc = currentMillis;
        attachInterrupt(digitalPinToInterrupt(IR_PIN), countPulse, FALLING);
    }

    // 2. Process Data every 5 seconds
    if (currentMillis - lastUpdate >= interval) {
        lastUpdate = currentMillis;

        readSensors();
        updateOLED(1, v_buffer[0], i_buffer[0], vibState);

        if (wifiConnected) {
            uploadJSON(v_buffer, i_buffer, vibState, currentRPM);
        }
    }
}

void updateOLED(int port, float v, float i, int vib) {
    display.clearDisplay();
    // Header
    display.fillRect(0, 0, 128, 14, SSD1306_WHITE);
    display.setTextColor(SSD1306_BLACK);
    display.setCursor(4, 3);
    display.setTextSize(1);
    display.printf("PORT %d | RPM: %d", port, currentRPM);

    // Main Values
    display.setTextColor(SSD1306_WHITE);
    display.setCursor(0, 22);
    display.setTextSize(2);
    display.printf("%.1fV", v);
    display.setCursor(70, 22);
    display.printf("%.1fA", i);

    // Footer
    display.drawFastHLine(0, 42, 128, SSD1306_WHITE);
    display.setTextSize(1);
    display.setCursor(0, 50);
    display.printf("VIB: %s", vib ? "ACTIVE" : "OK");
    display.setCursor(85, 50);
    display.printf("[%s]", wifiConnected ? "WiFi" : "OFF");
    display.display();
}

void uploadJSON(float v[], float i_arr[], int vib, int rpm) {
    HTTPClient http;
    http.begin(serverURL);
    http.addHeader("Content-Type", "application/json");

    StaticJsonDocument<512> doc;
    JsonArray ports = doc.createNestedArray("ports");
    
    // Safety check: Loop through the ports
    for (int j = 0; j < 2; j++) {
        JsonObject p = ports.createNestedObject();
        p["port"] = j + 1;
        p["voltage"] = serialized(String(v[j], 1));

        // FIXED: Using if-else instead of ternary to avoid type mismatch error
        if (j < 1) {
            p["current"] = serialized(String(i_arr[j], 1));
        } else {
            p["current"] = 0;
        }
    }
    doc["vibration"] = vib;
    doc["rpm"] = rpm;

    String payload;
    serializeJson(doc, payload);
    
    int httpResponseCode = http.POST(payload);
    Serial.printf("HTTP Response code: %d\n", httpResponseCode);
    
    http.end();
}

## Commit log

2025-12-21 code doc done & intro updated
    [Part1.stl, Part2.stl]
2025-12-22 fixed dashboard button
2025-12-23 combined PCB n Firmware
    [0.96 OLED Module - i2C.stp, IRsensors.STEP, MICRO-SD-CARD.step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]
